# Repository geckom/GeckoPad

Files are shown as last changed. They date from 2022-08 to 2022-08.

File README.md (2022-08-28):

# GeckoPad

intro

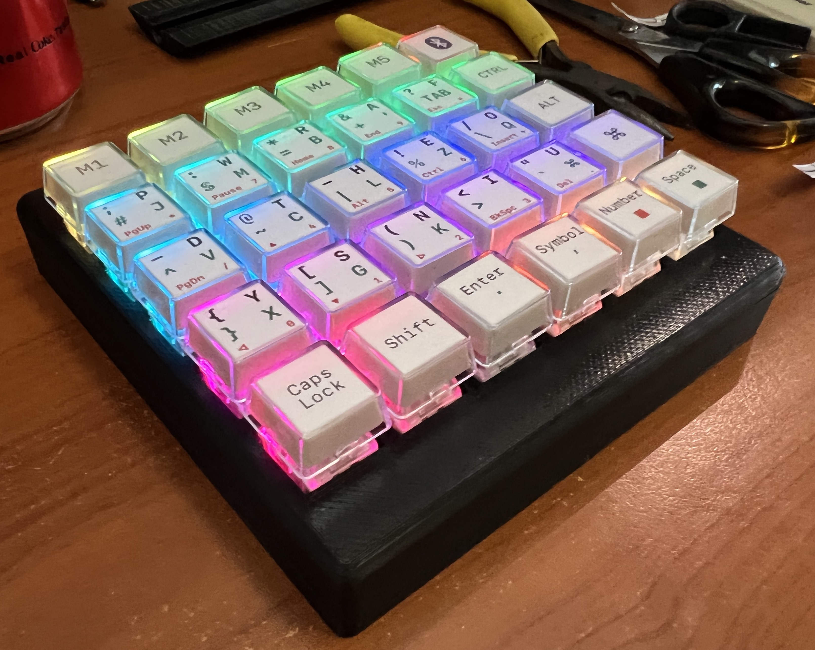
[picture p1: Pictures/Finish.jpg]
Finished Version


inspiration

other one handed keyboard

Features:

- Glowing keys with configurable light patterns
- Bluetooth and USB
- Battery powered with USB recharging
- Auto deep sleep after 5 minutes

# Design Goals!

test

# Parts

All parts were ordered from [Little Bird Electronics](https://littlebirdelectronics.com.au/) in Australian. Checkout [Adafruit](https://www.adafruit.com/) for internationally shipped parts.

| Part | Qty | Price | Total |
| --- | --- | --- | --- |
| [Relegendable Plastic Keycaps for MX Compatible Switches 10 pack](https://littlebirdelectronics.com.au/products/relegendable-plastic-keycaps-for-mx-compatible-switches-10-pack) | 3 | AUD$7.41 | AUD$22.23 |
| [NeoKey 5x6 Ortho Snap-Apart Mechanical Key Switches w/ NeoPixel - For MX Compatible Switches](https://littlebirdelectronics.com.au/products/neokey-5x6-ortho-snap-apart-mechanical-key-switches-w-neopixel-for-mx-compatible-switches) | 1 | AUD$48.00 | AUD$48.00 |
| [Kailh Mechanical Key Switches - Tactile Brown - 10 pack - Cherry MX Brown Compatible](https://littlebirdelectronics.com.au/products/kailh-mechanical-key-switches-tactile-brown-10-pack-cherry-mx-brown-compatible) | 3 | AUD$12.00 | AUD$36.00 |
| [40 pin 30CM Jumper wire M/M](https://littlebirdelectronics.com.au/products/40-pin-30cm-jumper-wire-m-m) | 1 | AUD$3.30 | AUD$3.30 |
| [Adafruit Feather M0 Bluefruit LE](https://littlebirdelectronics.com.au/products/adafruit-feather-m0-bluefruit-le) | 1 | AUD$67.58 | AUD$67.58 |
| 1,000mAh lipo battery (already had) | 1 | AUD$0.00 | AUD$0.00 |
| | | | AUD$177.11 |

# Design of plastic body

The original design had mounting clips so that the top and bottom bodies would snap into place. However the tolerances of the groovy to ensure they line up proved to be enough to hold the parts together securely while simplifying the design. All of the designing was done in AutoDesk Fusion 360 and the design files are included along with STL exports so new versions can be 3d printed.

The bottom case was design so the Feather M0 would simply snap into place with extra reinforcement to handle the load from the USB plug being inserted and removed regularly. The battery is held in place securely with 4 walls and is held down by the bottom of the NeoKey PCB. The NeoKey Screws into place tightly with M3 8mm screws. There is extra length allowed for longer screws if required.

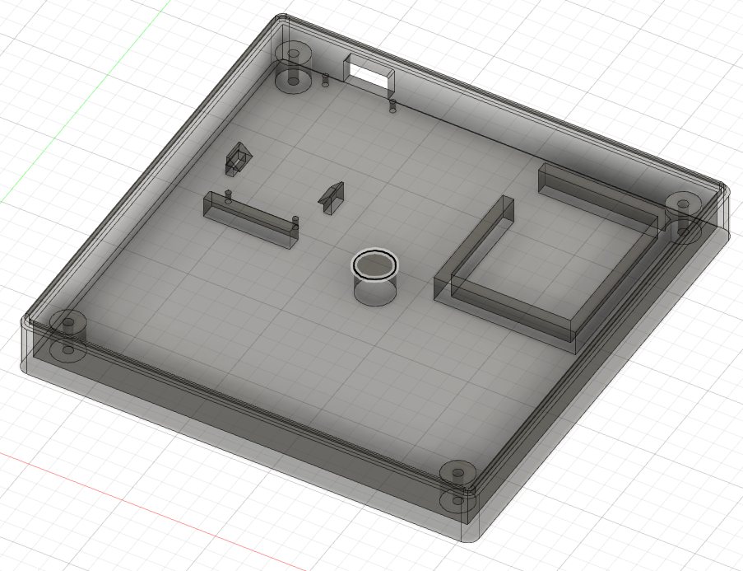
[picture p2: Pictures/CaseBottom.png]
Case Bottom


The top of the 3d printed casing was designed to simply snap onto the top of the bottom body and hide the PCB shown between the keys. The top edges were filleted to ensure the is no rough edges near the users hand. Since all of the components are attached to the bottom body, there is very little load to the top face plate.

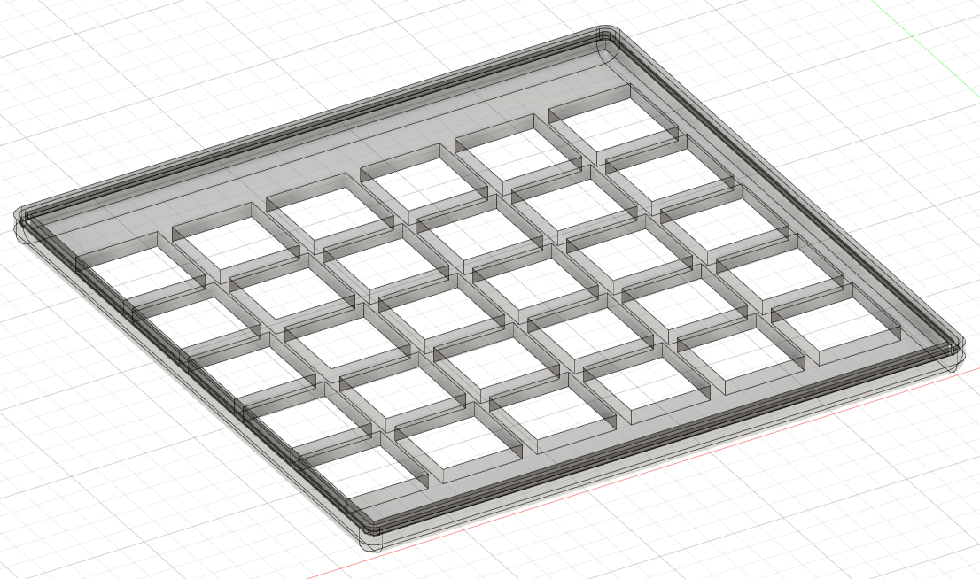
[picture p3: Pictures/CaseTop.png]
Case Top


# Keyboard Layout Design

This was heavily based on the FrogPad keyboard layout which is no longer available.

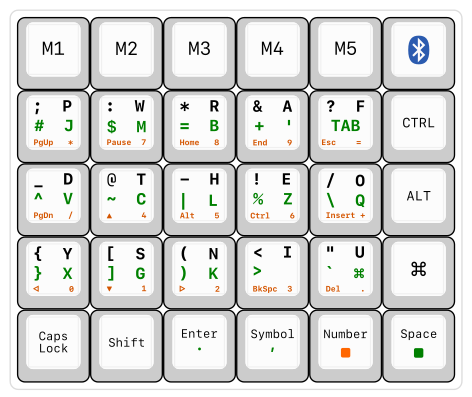
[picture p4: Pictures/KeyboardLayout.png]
Keyboard Layout


# Firmware

The Arduino firmware files are included in the ArduinoCode directory and contain a fully working keyboard firmware. The firmware is designed to work with a Adafruit Feather M0 Bluefruit LE chip.

Borrowed chuncks of code from https://github.com/clc/chorder

# Build

test

# Testing

Battery was found to last a few days with the LEDs rotating colours.

# Typing Speed / WPM

It was said with the FrogPad that some one could learn to type at 40WPM in 8 to 15 hours. I created a HTML webpage to learn the keys originally then quickly moved to using typing.com to improve my typing speed once the keys were learnt. The KeyLearner can be run from any PC by double clicking on the index.html file or uploaded to a webserver. Learning was done on an iPhone, iPad, Mac and Windows PC. My average WPM on a standard keyboard is approximately 75 WPM when starting to learn to type on the GeckoPad.

| Day | Where | Time | WPM |
| --- | --- | --- | --- |
| Day 1 | KeyLearner | 15min | |
| Day 2 | | | |
| Day 3 | | | |
| Day 4 | | | |

# Future Improvements

The keyboard high is 35mm which is 5mm over the ISO standard for keyboards. While I could probably reduce the height another 5mm, in a future design I would move the battery and Arduino out from under the keyboard PCB to drastically reduce the key height. Additionally, in a future version, I would replace the lip battery with an easily replaceable 3,000mAh 18650 cell common used in vapes. This would triple the battery life and make it easy to replace when the battery degrades.

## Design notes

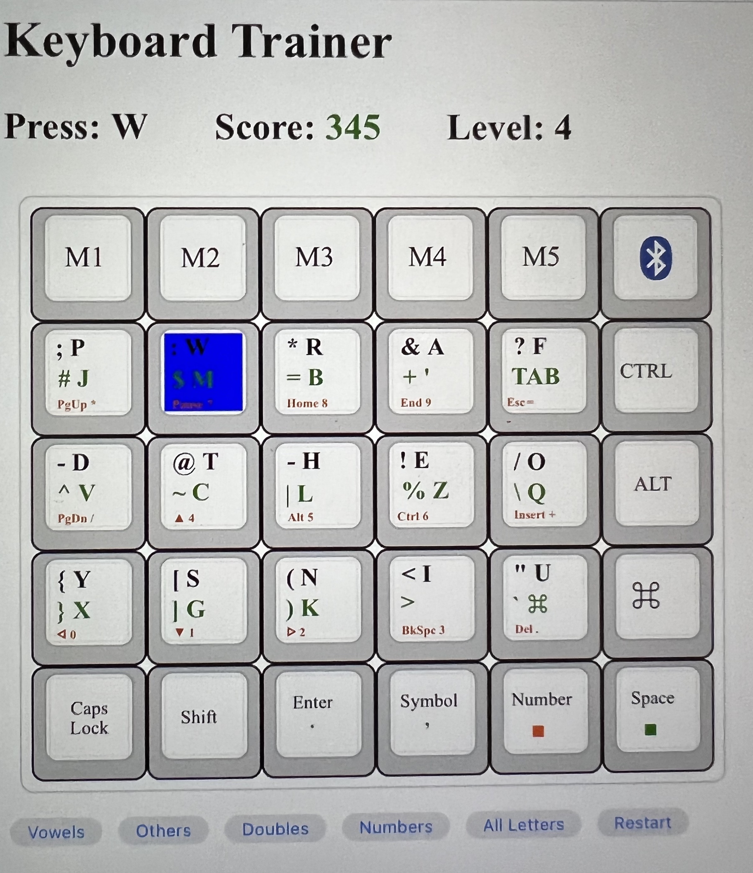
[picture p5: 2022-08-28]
Pictures/KeyTrainer.jpg

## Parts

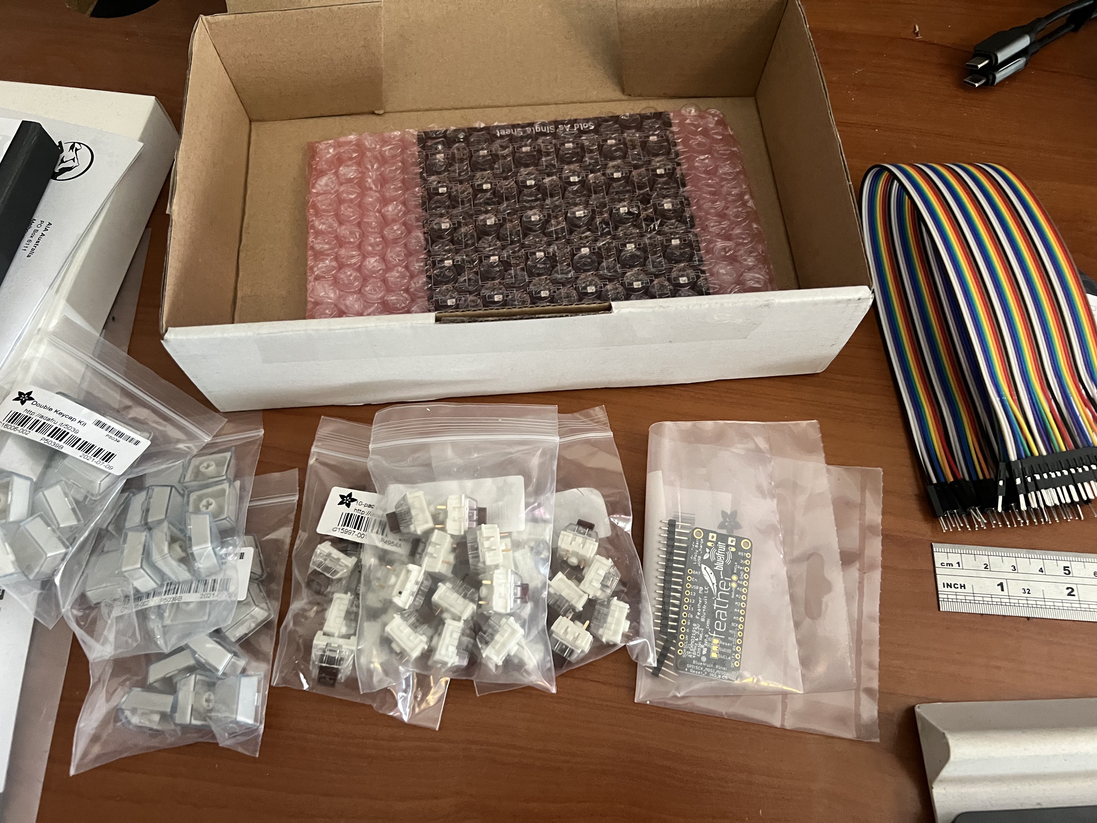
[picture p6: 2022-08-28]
Pictures/Parts.jpg

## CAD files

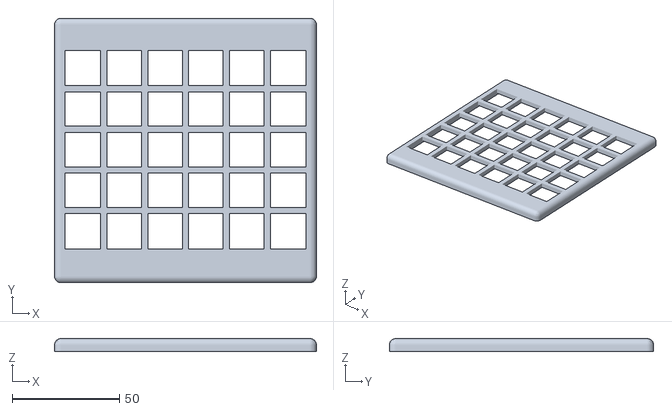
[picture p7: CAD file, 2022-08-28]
BodyDesign/TopBody.stl
122.4 x 123.5 x 6.00

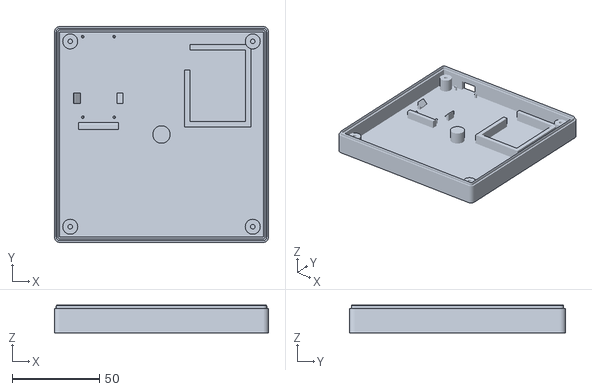
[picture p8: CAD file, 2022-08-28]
BodyDesign/BottomBody.stl
122.4 x 123.5 x 16.0

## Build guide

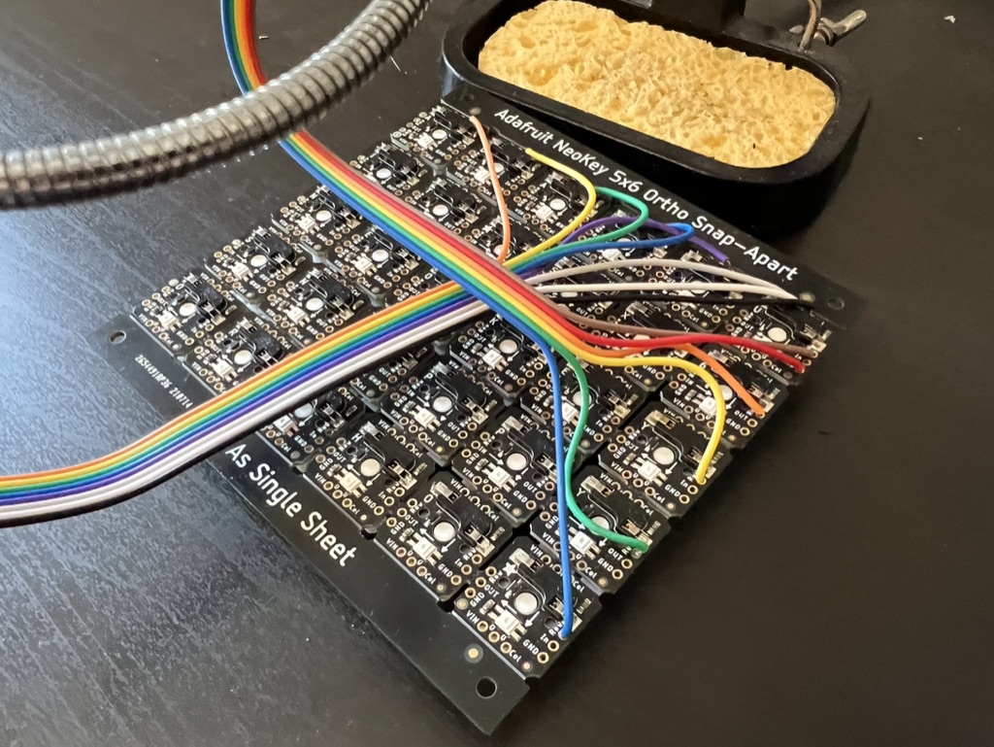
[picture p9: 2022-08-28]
Pictures/Wiring.jpg

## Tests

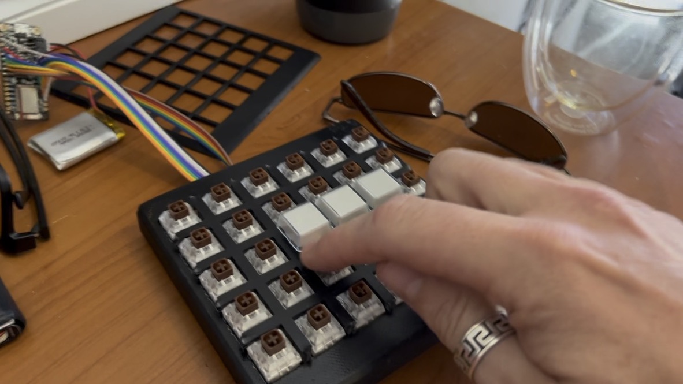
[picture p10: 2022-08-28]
Pictures/Testing2.jpg

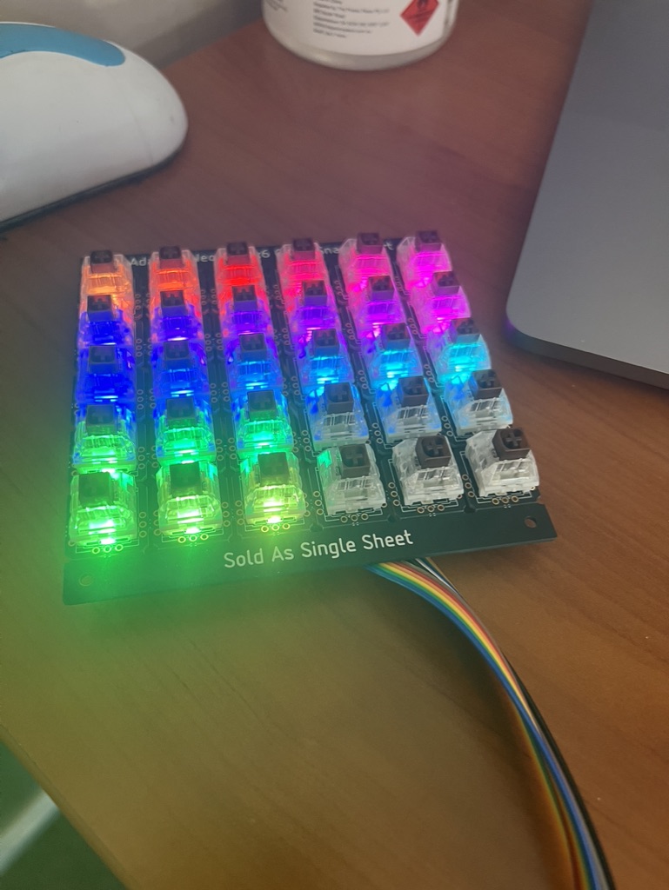
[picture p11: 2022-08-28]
Pictures/Testing.jpg

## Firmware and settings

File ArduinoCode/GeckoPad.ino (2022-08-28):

// GeckoPad Firmware v1

#include <Keyboard.h>
#include "ArduinoLowPower.h"
#include "KeyCodes.h"

// BLUETOOTH SETUP
#include <Arduino.h>
#include <SPI.h>
#include "Adafruit_BLE.h"
#include "Adafruit_BluefruitLE_SPI.h"
#include "Adafruit_BluefruitLE_UART.h"
#include "BluefruitConfig.h"
//#if SOFTWARE_SERIAL_AVAILABLE
//  #include <SoftwareSerial.h>
//#endif
#define FACTORYRESET_ENABLE         0
#define MINIMUM_FIRMWARE_VERSION    "0.6.6"
#define VERBOSE_MODE                1
/* ...hardware SPI, using SCK/MOSI/MISO hardware SPI pins and then user selected CS/IRQ/RST */
Adafruit_BluefruitLE_SPI ble(BLUEFRUIT_SPI_CS, BLUEFRUIT_SPI_IRQ, BLUEFRUIT_SPI_RST);
bool BluetoothOn = 0;

// NEO PIXEL SETUP
#include <Adafruit_NeoPixel.h>
#include "Adafruit_Keypad.h"
#define ROWS 5 // rows
#define COLS 6 // columns
#define NEOPIXEL_PIN 5
#define NUM_PIXELS (ROWS * COLS)
Adafruit_NeoPixel strip = Adafruit_NeoPixel(NUM_PIXELS, NEOPIXEL_PIN, NEO_GRB + NEO_KHZ800);
uint8_t rowPins[ROWS] = {18, 17, 16, 15, 14}; //connect to the row pinouts of the keypad
uint8_t colPins[COLS] = {13, 12, 11, 10, 9, 6}; //connect to the column pinouts of the keypad
bool lit[ROWS * COLS] = {0};


//define the symbols on the buttons of the keypads
const keymap_t keys[ROWS][COLS] = {
  {MODE_OTHER,  MODE_NUM,   MODE_SYM,   ENUMKEY_enter,  MOD_LSHIFT, ENUMKEY_cpslck},
  {MOD_LGUI,    ENUMKEY_U,  ENUMKEY_I,  ENUMKEY_N,  ENUMKEY_S,  ENUMKEY_Y},
  {MOD_LALT,    ENUMKEY_O,  ENUMKEY_E,  ENUMKEY_H,  ENUMKEY_T,  ENUMKEY_D},
  {MOD_LCTRL,   ENUMKEY_F,  ENUMKEY_A,  ENUMKEY_R,  ENUMKEY_W,  ENUMKEY_P},
  {MODE_INPUT,  MODE_M5,    MODE_M4,    MODE_M3,    MODE_M2,    MODE_M1}
};

const keymap_t otherkeys[ROWS][COLS] = {
  {MODE_OTHER,  MODE_NUM,   ENUMKEY_comma,  ENUMKEY_dot,  MOD_LSHIFT, ENUMKEY_cpslck},
  {MOD_LGUI,    MOD_LGUI,   ENUMKEY__,      ENUMKEY_K,    ENUMKEY_G,  ENUMKEY_X},
  {MOD_LALT,    ENUMKEY_Q,  ENUMKEY_Z,      ENUMKEY_L,    ENUMKEY_C,  ENUMKEY_V},
  {MOD_LCTRL,   ENUMKEY_tab,ENUMKEY_ping,   ENUMKEY_B,    ENUMKEY_M,  ENUMKEY_J},
  {MODE_INPUT,  MODE_M5,    MODE_M4,        MODE_M3,      MODE_M2,    MODE_M1}
};

const keymap_t numkeys[ROWS][COLS] = {
  {MODE_OTHER,  MODE_NUM,       MODE_SYM,   ENUMKEY_enter,  MOD_LSHIFT, ENUMKEY_cpslck},
  {MOD_LGUI,    ENUMKEY_dot,    ENUMKEY_3,  ENUMKEY_2,      ENUMKEY_1,  ENUMKEY_0},
  {MOD_LALT,    MACRO_plus,     ENUMKEY_6,  ENUMKEY_5,      ENUMKEY_4,  ENUMKEY_slash},
  {MOD_LCTRL,   ENUMKEY_equal,  ENUMKEY_9,  ENUMKEY_8,      ENUMKEY_7,  MACRO_asterisk},
  {MODE_INPUT,  MODE_M5,        MODE_M4,    MODE_M3,        MODE_M2,    MODE_M1}
};

const keymap_t symkeys[ROWS][COLS] = {
  {MODE_OTHER,  MODE_NUM,       MODE_SYM,         ENUMKEY_enter,    MOD_LSHIFT,   ENUMKEY_cpslck},
  {MOD_LGUI,    MACRO_quotes,   MACRO_lt,         MACRO_openparen,  ENUMKEY_lbr,  MACRO_opencurly},
  {MOD_LALT,    ENUMKEY_slash,  MACRO_exclamation,ENUMKEY_minus,    MACRO_atsign, MACRO_underscore},
  {MOD_LCTRL,   MACRO_question, MACRO_ampersand,  MACRO_asterisk,   MACRO_colon,  ENUMKEY_smcol},
  {MODE_INPUT,  MODE_M5,        MODE_M4,          MODE_M3,          MODE_M2,      MODE_M1}
};

const keymap_t symotherkeys[ROWS][COLS] = {
  {MODE_OTHER,  MODE_NUM,       MODE_SYM,         ENUMKEY_enter,    MOD_LSHIFT,   ENUMKEY_cpslck},
  {MOD_LGUI,    ENUMKEY_grave,  MACRO_gt,         MACRO_closeparen, ENUMKEY_rbr,  MACRO_closecurly},
  {MOD_LALT,    ENUMKEY_bckslsh,MACRO_percent,    MACRO_pipe,       MACRO_tilde,  MACRO_caret},
  {MOD_LCTRL,   ENUMKEY_tab,    MACRO_plus,       ENUMKEY_equal,    MACRO_dollar, MACRO_hash},
  {MODE_INPUT,  MODE_M5,        MODE_M4,          MODE_M3,          MODE_M2,      MODE_M1}
};

const keymap_t funckeys[ROWS][COLS] = {
  {MODE_OTHER,  MODE_NUM,     MODE_SYM,       ENUMKEY_enter,  MOD_LSHIFT,   ENUMKEY_cpslck},
  {MOD_LGUI,    ENUMKEY_del,  ENUMKEY_bckspc, ENUMKEY_rarr,   ENUMKEY_darr, ENUMKEY_larr},
  {MOD_LALT,    ENUMKEY_ins,  MOD_LCTRL,      MOD_LALT,       ENUMKEY_uarr, ENUMKEY_pgdn},
  {MOD_LCTRL,   ENUMKEY_esc,  ENUMKEY_end,    ENUMKEY_home,   ENUMKEY_break,ENUMKEY_pgup},
  {MODE_INPUT,  MODE_M5,      MODE_M4,        MODE_M3,        MODE_M2,      MODE_M1}
};


//initialize an instance of class NewKeypad
Adafruit_Keypad customKeypad = Adafruit_Keypad( makeKeymap(keys), rowPins, colPins, ROWS, COLS);

enum InputMode {
  USBINPUT,
  BLUETOOTH
};
InputMode inputMode = USBINPUT;
enum ColourMode {
  RAINBOW,
  FADE,
  FADEBLUE,
  FADEPURPLE,
  FADEGREEN
};
ColourMode colourMode = FADE;
enum Mode {
  ALPHA,
  OTHER,
  NUM,
  SYM,
  FUNCTION
};
Mode mode = ALPHA;

bool keySent = false;

bool isCapsLocked = false;
bool isNumLocked = false;
bool isSymLocked = false;

bool isCTRL = false;
bool isALT = false;
bool isSHIFT = false;
bool isGUI = false;


keymap_t modKeys = 0x00;



// TIMEING SETUP
unsigned long startMillis;  //some global variables available anywhere in the program
unsigned long currentMillis;
const unsigned long period = 300*1000;  //the value is a number of milliseconds

void setup() {

  pinMode(LED_BUILTIN, OUTPUT);
  digitalWrite(LED_BUILTIN, HIGH);   // turn the LED on (HIGH is the voltage level)

  Serial.begin(115200);
  //while (!Serial);
  Serial.println("GeckoPad");
  strip.begin();
  strip.setBrightness(40);
  strip.show(); // Initialize all pixels to 'off'

  customKeypad.begin();
  for (int i = 0; i < ROWS * COLS; i++) {
    lit[i] = false;
  }
  delay(3000);
  Keyboard.begin();

  
  startMillis = millis();  //initial start time

}

uint8_t j = 0; // color ticker

void loop() {
  currentMillis = millis();  //get the current "time" (actually the number of milliseconds since the program started)
  //Serial.println("Test NeoPixels");
  customKeypad.tick();

  while (customKeypad.available()) {
    keypadEvent e = customKeypad.read();
    Serial.print((char)e.bit.KEY);
    if (e.bit.EVENT == KEY_JUST_PRESSED) {
      Serial.println(" pressed");
      uint8_t row = e.bit.ROW;
      uint8_t col = e.bit.COL;
      Serial.print("Row: "); Serial.print(row);
      Serial.print(" col: "); Serial.print(col);
      Serial.print(" -> ");
      uint16_t keynum;
      if (row % 2 == 0) { // even row
        keynum = row * COLS + col;
      } else { // odd row the neopixels go BACKWARDS!
        keynum = row * COLS + (5 - col);
      }
      Serial.println(keynum);
      initialLightKey(keynum);
      sendKeystroke(e, row, col);
      
      startMillis = currentMillis;  //IMPORTANT to save the start time of the current LED state.
    }
    else if (e.bit.EVENT == KEY_JUST_RELEASED) {
      Serial.println(" released");
      uint8_t row = e.bit.ROW;
      uint8_t col = e.bit.COL;
      sendRelease(e, row, col);
    }
  }

  setKeyColour();
  
  if (currentMillis - startMillis >= period)  //test whether the period has elapsed
  {
    gotoSleep();
  }
}





void sendKeystroke(keypadEvent e, uint8_t row, uint8_t col) {
//      if (customKeypad.isPressed(' ') and (char)e.bit.KEY != ' ') {
//          sendKeystroke2((char)spckeys[row][col]);
//          Space = 1;
//      } else if (Space == 1 and (char)e.bit.KEY == ' ') {
//        Space = 0;
//      } else if (customKeypad.isPressed(KEY_F24) and (char)e.bit.KEY != KEY_F24) {
//          sendKeystroke2((char)funckeys[row][col]);
//          Number = 1;
//      } else if (Number == 1 and (char)e.bit.KEY == KEY_F24) {
//        Number = 0;
//      } else if ((char)e.bit.KEY == KEY_LEFT_SHIFT) {
//        sendKeystroke2(KEY_LEFT_SHIFT);
//      } else if ((char)e.bit.KEY == 3) {
//        changeMode();
//      } else if ((char)e.bit.KEY == 65) {
//        ChangeColourMode();
//      } else if ((char)e.bit.KEY == KEY_LEFT_GUI) {
//        key_gui = !key_gui; // invert status
//      } else if ((char)e.bit.KEY == KEY_LEFT_CTRL) {
//        key_ctrl = !key_ctrl; // invert status
//      } else if ((char)e.bit.KEY == KEY_LEFT_ALT) {
//        key_alt = !key_alt; // invert status
//      } else { 
//        sendKeystroke2((char)e.bit.KEY);
//      }
  keySent = false;

  keymap_t theKey;
   if (mode == ALPHA) {
    if(isSymLocked) theKey = symkeys[row][col];
    else theKey = keys[row][col];
  } else if (mode == OTHER) {
    if(isSymLocked) theKey = symotherkeys[row][col];
    else theKey = otherkeys[row][col];
  } else if (mode == NUM and isNumLocked==false) {
    theKey = funckeys[row][col];
  } else if (mode == NUM and isNumLocked==true) {
    theKey = numkeys[row][col];
  }
  //symotherkeys
  switch (theKey)  {
    case MODE_INPUT:
      changeInputMode();
      return;
    case MODE_OTHER:
          mode = OTHER;
        return;
    case MODE_NUM:
        mode = NUM;
      return;
    case MODE_SYM:
      if (isSymLocked) {
        isSymLocked = false;
      } else {
        isSymLocked = true;
      }
      return;
    case MODE_FUNC:
      if (mode == FUNCTION) {
        mode = ALPHA;
        //isNumLocked = false;
      } else {
        mode = FUNCTION;
      }
      return;
    // Handle mode locks
    case ENUMKEY_cpslck:
      if (isCapsLocked){
        isCapsLocked = false;
        modKeys = 0x00;
      } else {
        isCapsLocked = true;
        modKeys = 0x02;
      }
      return;
    case MOD_LCTRL:
      modKeys = modKeys ^ 0x01;
      isCTRL = true;
      keySent = true;
      return;
    case MOD_LSHIFT:
      modKeys = modKeys ^ 0x02;
      isSHIFT = true;
      return;
    case MOD_LALT:
      modKeys = modKeys ^ 0x04;
      isALT = true;
      keySent = true;
      return;
    case MOD_LGUI:
      modKeys = modKeys ^ 0x08;
      isGUI = true;
      keySent = true;
      return;
    case MOD_RCTRL:
      modKeys = modKeys ^ 0x10;
      return;
    case MOD_RSHIFT:
      modKeys = modKeys ^ 0x20;
      return;
    case MOD_RALT:
      modKeys = modKeys ^ 0x40;
      return;
    case MOD_RGUI:
      modKeys = modKeys ^ 0x80;
      return;
    case MULTI_CtlAlt:
      modKeys = modKeys ^ 0x01;
      modKeys = modKeys ^ 0x04;
      return;
    /* Everything after this sends actual keys to the system; break rather than
       return since we want to reset the modifiers after these keys are sent. */
    case MACRO_000:
      sendRawKey(0x00, 0x27);
      sendRawKey(0x00, 0x27);
      sendRawKey(0x00, 0x27);
      break;
    case MACRO_00:
      sendRawKey(0x00, 0x27);
      sendRawKey(0x00, 0x27);
      break;
    case MACRO_quotes:
      sendRawKey(0x02, 0x34);
      break;
    case MACRO_parens:
      sendRawKey(0x02, 0x26);
      sendRawKey(0x02, 0x27);
      sendRawKey(0x00, 0x50);
      break;
    case MACRO_dollar:
      sendRawKey(0x02, 0x21);
      break;
    case MACRO_percent:
      sendRawKey(0x02, 0x22);
      break;
    case MACRO_ampersand:
      sendRawKey(0x02, 0x24);
      break;
    case MACRO_asterisk:
      sendRawKey(0x02, 0x25);
      break;
    case MACRO_question:
      sendRawKey(0x02, 0x38);
      break;
    case MACRO_plus:
      sendRawKey(0x02, 0x2E);
      break;
    case MACRO_openparen:
      sendRawKey(0x02, 0x26);
      break;
    case MACRO_closeparen:
      sendRawKey(0x02, 0x27);
      break;
    case MACRO_opencurly:
      sendRawKey(0x02, 0x2F);
      break;
    case MACRO_closecurly:
      sendRawKey(0x02, 0x30);
      break;
    case MACRO_exclamation:
      sendRawKey(0x02, 0x1E);
      break;
    case MACRO_atsign:
      sendRawKey(0x02, 0x1F);
      break;
    case MACRO_gt:
      sendRawKey(0x02, 0x37);
      break;
    case MACRO_lt:
      sendRawKey(0x02, 0x36);
      break;
    case MACRO_colon:
      sendRawKey(0x02, 0x33);
      break;
    case MACRO_pipe:
      sendRawKey(0x02, 0x31);
      break;
    case MACRO_tilde:
      sendRawKey(0x02, 0x35);
      break;
    case MACRO_caret:
      sendRawKey(0x02, 0x23);
      break;
    case MACRO_hash:
      sendRawKey(0x02, 0x20);
      break;
    case MACRO_underscore:
      sendRawKey(0x02, 0x2D);
      break;
    // MODE BUTTONS M1 to M5
    case MODE_M1:
      ChangeColourMode();
      return;
    case MODE_M2:
      return;
    case MODE_M3:
      return;
    case MODE_M4:
      return;
    case MODE_M5:
      return;

      
    // Send the key
    default:
      sendRawKey(modKeys, theKey);
      break;
    
  }
  modKeys = 0x00;
  isCTRL = false;
  isALT = false;
  isSHIFT = false;
  isGUI = false;
  //mode = ALPHA;
  // Reset the modKeys and mode based on locks
  if (isCapsLocked){
    modKeys = 0x02;
  }
//  if (isNumLocked){
//    mode = NUM;
//  }
//  if (isSymLocked){
//    mode = SYM;
//  }
}

void sendRawKey(char modKey, char rawKey){
  keySent = true;
  // Format for Bluefruit Feather is MOD-00-KEY.
  String keys = String(modKey, HEX) + "-00-" + String(rawKey, HEX);
  
  ble.print("AT+BLEKEYBOARDCODE=");
  ble.println(keys);
  // Must send this to release the keys.
  ble.println("AT+BLEKEYBOARDCODE=00-00");
}

void sendRelease(keypadEvent e, uint8_t row, uint8_t col) {
  keymap_t theKey;
   if (mode == ALPHA) {
    theKey = keys[row][col];
  } else if (mode == OTHER) {
    theKey = otherkeys[row][col];
  } else if (mode == NUM and isNumLocked==false) {
    theKey = funckeys[row][col];
  } else if (mode == NUM and isNumLocked==true) {
    theKey = numkeys[row][col];
  } else if (mode == SYM) {
    theKey = symkeys[row][col];
  } else {
    theKey = funckeys[row][col];
  }
 switch (theKey)  {
    case MODE_OTHER:
      if (mode == OTHER) {
        mode = ALPHA;
      }
      if( keySent == false) {
        sendRawKey(ENUMKEY__, ENUMKEY_spc);  // send space key
      }
      return;
    case MODE_NUM:
      if( keySent == false and isNumLocked == false) {
        isNumLocked = true;
      } else {
        isNumLocked = false;
        mode = ALPHA;
      }
      return;
    default:
      break;
  }
}

//void sendKeystroke2(char key) {
//  if(inputMode == USBINPUT) {
//    Keyboard.write((char)key);
//  } else {
//      sendBluetoothKey(key);
//  }
//}

void changeInputMode() {
  if(inputMode == BLUETOOTH ) {
    inputMode = USBINPUT;
  } else {
    inputMode = BLUETOOTH;
  }
  
  if(inputMode == USBINPUT) {
    ble.end();
    BluetoothOn = 0;
  }
  if(inputMode == BLUETOOTH and BluetoothOn==0) {
    setupBluetooth();
    BluetoothOn = 1;
  }
}


//////////////////////////////////////////////////////////////
///////////////////////// BLUETOOTH //////////////////////////
//////////////////////////////////////////////////////////////

// A small helper
void error(const __FlashStringHelper*err) {
  Serial.println(err);
  //while (1);
}

void setupBluetooth() {
  delay(500);

  
  /* Initialise the module */
  Serial.print(F("Initialising the Bluefruit LE module: "));

  if ( !ble.begin(VERBOSE_MODE) )
  {
    error(F("Couldn't find Bluefruit, make sure it's in CoMmanD mode & check wiring?"));
  }
  Serial.println( F("OK!") );

  if ( FACTORYRESET_ENABLE )
  {
    /* Perform a factory reset to make sure everything is in a known state */
    Serial.println(F("Performing a factory reset: "));
    if ( ! ble.factoryReset() ){
      error(F("Couldn't factory reset"));
    }
  }

  /* Disable command echo from Bluefruit */
  ble.echo(false);

  Serial.println("Requesting Bluefruit info:");
  /* Print Bluefruit information */
  ble.info();

  /* Change the device name to make it easier to find */
  Serial.println(F("Setting device name to 'GeckoPad Keyboard': "));
  if (! ble.sendCommandCheckOK(F( "AT+GAPDEVNAME=GeckoPad" )) ) {
    error(F("Could not set device name?"));
  }

  /* Enable HID Service */
  Serial.println(F("Enable HID Service (including Keyboard): "));
  if ( ble.isVersionAtLeast(MINIMUM_FIRMWARE_VERSION) )
  {
    if ( !ble.sendCommandCheckOK(F( "AT+BleHIDEn=On" ))) {
      error(F("Could not enable Keyboard"));
    }
  }else
  {
    if (! ble.sendCommandCheckOK(F( "AT+BleKeyboardEn=On"  ))) {
      error(F("Could not enable Keyboard"));
    }
  }

  /* Add or remove service requires a reset */
  Serial.println(F("Performing a SW reset (service changes require a reset): "));
  if (! ble.reset() ) {
    error(F("Couldn't reset??"));
  }

  Serial.println();
  Serial.println(F("Go to your phone's Bluetooth settings to pair your device"));
  Serial.println(F("then open an application that accepts keyboard input"));

  Serial.println();
  

}


//////////////////////////////////////////////////////////////
///////////////////////// COLOURING //////////////////////////
//////////////////////////////////////////////////////////////

void initialLightKey(int keynum) {
  if (colourMode == FADE) {
    strip.setPixelColor(keynum, strip.Color( random(0, 255),  random(0, 255),  random(0, 255)));
    lit[keynum] = 1;
  } else if (colourMode == FADEBLUE) {
    strip.setPixelColor(keynum, strip.Color( 0,  0,  255));
    lit[keynum] = 1;
  } else if (colourMode == FADEPURPLE) {
    strip.setPixelColor(keynum, strip.Color( 150,  50,  255));
    lit[keynum] = 1;
  } else if (colourMode == FADEGREEN) {
    strip.setPixelColor(keynum, strip.Color( 0,  255,  0));
    lit[keynum] = 1;
  } else {
    lit[keynum] = !lit[keynum]; // invert neopixel status
  }
}

void setKeyColour() {
  for(int i=0; i< strip.numPixels(); i++) {
    if(i == 23) {  // CTRL
      if(isCTRL) {
        strip.setPixelColor(i, 255, 0, 0);
      } else {
        strip.setPixelColor(i, 0, 0, 0);
      }
    } else if(i == 12) {  // ALT
      if(isALT) {
        strip.setPixelColor(i, 255, 0, 0);
      } else {
        strip.setPixelColor(i, 0, 0, 0);
      }
    } else if(i == 11) {  // GUI
      if(isGUI) {
        strip.setPixelColor(i, 255, 0, 0);
      } else {
        strip.setPixelColor(i, 0, 0, 0);
      }
    } else if(i == 4) {  // SHIFT
      if(isSHIFT) {
        strip.setPixelColor(i, 255, 0, 0);
      } else {
        strip.setPixelColor(i, 0, 0, 0);
      }
    } else if(i == 5) {  // CAPS
      if(isCapsLocked) {
        strip.setPixelColor(i, 255, 0, 0);
      } else {
        strip.setPixelColor(i, 0, 0, 0);
      }
    } else if(i == 2) {  // SYMBOL MODE
      if(isSymLocked) {
        strip.setPixelColor(i, 255, 0, 0);
      } else {
        strip.setPixelColor(i, 0, 0, 0);
      }
    } else if(i == 1) {  // NUMBER MODE
      if(isNumLocked or mode == NUM) {
        strip.setPixelColor(i, 255, 0, 0);
      } else {
        strip.setPixelColor(i, 0, 0, 0);
      }
    } else if(i == 24) {
      if(inputMode == USBINPUT) {
        strip.setPixelColor(i, 255, 0, 0);
      } else if(inputMode == BLUETOOTH) {
        strip.setPixelColor(i, 0, 0, 255);
      }
    } else if(i == 29) {  // M1
      if(colourMode == RAINBOW) strip.setPixelColor(i, Wheel(((i * 256 / strip.numPixels()) + j) & 255));
      else if(colourMode == FADE) strip.setPixelColor(i, Wheel(((i * 256 / strip.numPixels()) + j) & 255));
      else if(colourMode == FADEBLUE) strip.setPixelColor(i, 0, 0, 255);
      else if(colourMode == FADEPURPLE) strip.setPixelColor(i, 150,  50,  255);
      else if(colourMode == FADEGREEN) strip.setPixelColor(i, 0, 255, 0);
      else strip.setPixelColor(i, 0, 0, 0);
//    } else if(i == 28) {  // M2
//      if(colourMode == FADE) strip.setPixelColor(i, 255, 0, 0);
//      else strip.setPixelColor(i, 0, 0, 0);
//    } else if(i == 27) {  // M3
//      if(colourMode == FADEBLUE) strip.setPixelColor(i, 0, 0, 255);
//      else strip.setPixelColor(i, 0, 0, 0);
//    } else if(i == 26) {  // M4
//      if(colourMode == FADEPURPLE) strip.setPixelColor(i, 150,  50,  255);
//      else strip.setPixelColor(i, 0, 0, 0);
//    } else if(i == 25) {  // M5
//      if(colourMode == FADEGREEN) strip.setPixelColor(i, 0, 255, 0);
//      else strip.setPixelColor(i, 0, 0, 0);
    } else if (lit[i]) {
      if (colourMode != RAINBOW) {
        // random colour dimming dtdddtdwthprtdwetdwthrwdtptwhesarnsui
        strip.setPixelColor(i,DimColor(i));  // Dim out the random colour
        delay(10);
      } else {
        strip.setPixelColor(i, Wheel(((i * 256 / strip.numPixels()) + j) & 255));
      }
    } else {
      strip.setPixelColor(i, 0);
    }
  }
  strip.show();
  j++;
  delay(10);
}

// Calculate 50% dimmed version of a color (used by ScannerUpdate)
uint32_t DimColor(int i)
{
  uint32_t ColorOfThePixel = strip.getPixelColor(i);
  uint8_t r = Red(ColorOfThePixel);
  uint8_t g = Green(ColorOfThePixel);
  uint8_t b = Blue(ColorOfThePixel);
  if (r == 0 and g == 0 and b == 0) {
    lit[i] = !lit[i]; // invert neopixel status
  }
  // Shift R, G and B components one bit to the right
  uint32_t dimColor = strip.Color(r, g, b);
  return dimColor;
}

// Returns the Red component of a 32-bit color
uint8_t Red(uint32_t color)
{
    return (color >> 16) & 0xFF;
}
// Returns the Green component of a 32-bit color
uint8_t Green(uint32_t color)
{
    return (color >> 8) & 0xFF;
}
// Returns the Blue component of a 32-bit color
uint8_t Blue(uint32_t color)
{
    return color & 0xFF;
}
//
void ChangeColourMode() {
  Serial.println("Changing colour mode.."); 
  if(colourMode == RAINBOW)           colourMode = FADE;
  else if (colourMode == FADE)        colourMode = FADEBLUE;
  else if (colourMode == FADEBLUE)    colourMode = FADEPURPLE;
  else if (colourMode == FADEPURPLE)  colourMode = FADEGREEN;
  else colourMode = RAINBOW;
}

// Input a value 0 to 255 to get a color value.
// The colours are a transition r - g - b - back to r.
uint32_t Wheel(byte WheelPos) {
  if (WheelPos < 85) {
    return strip.Color(WheelPos * 3, 255 - WheelPos * 3, 0);
  } else if (WheelPos < 170) {
    WheelPos -= 85;
    return strip.Color(255 - WheelPos * 3, 0, WheelPos * 3);
  } else {
    WheelPos -= 170;
    return strip.Color(0, WheelPos * 3, 255 - WheelPos * 3);
  }
}



//////////////////////////////////////////////////////////////
////////////////////////// SLEEPING //////////////////////////
//////////////////////////////////////////////////////////////
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
